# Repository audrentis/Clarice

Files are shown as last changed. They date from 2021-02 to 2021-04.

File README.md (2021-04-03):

# Clarice-F103

## About
An Alice layout PCB based on Yuktsi's files

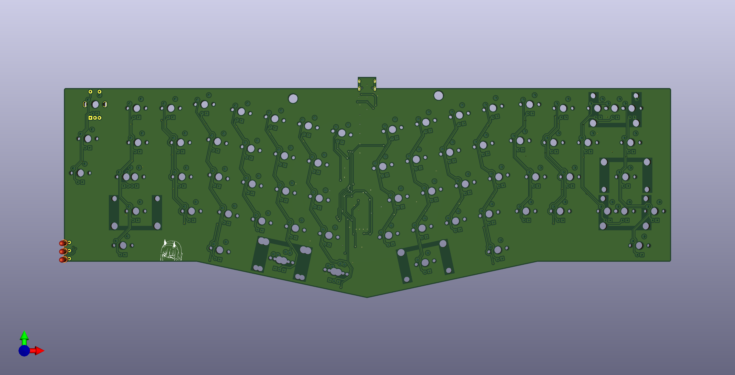
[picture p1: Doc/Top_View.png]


### PCB Features
* Bottom mount USB Type-C 
* Uses STM32F103 MCU
* Support for in-switch LEDs 
* 3 indicator lights in original positions 
* Rotary Encoder footprint at top of macro cluster
* Markings on F.Cu and B.Silks for different switch and stabilizer positions

Uses [xyzz's STM32F103 Bootloader](https://github.com/xyzz/stm32f103-keyboard-bootloader)

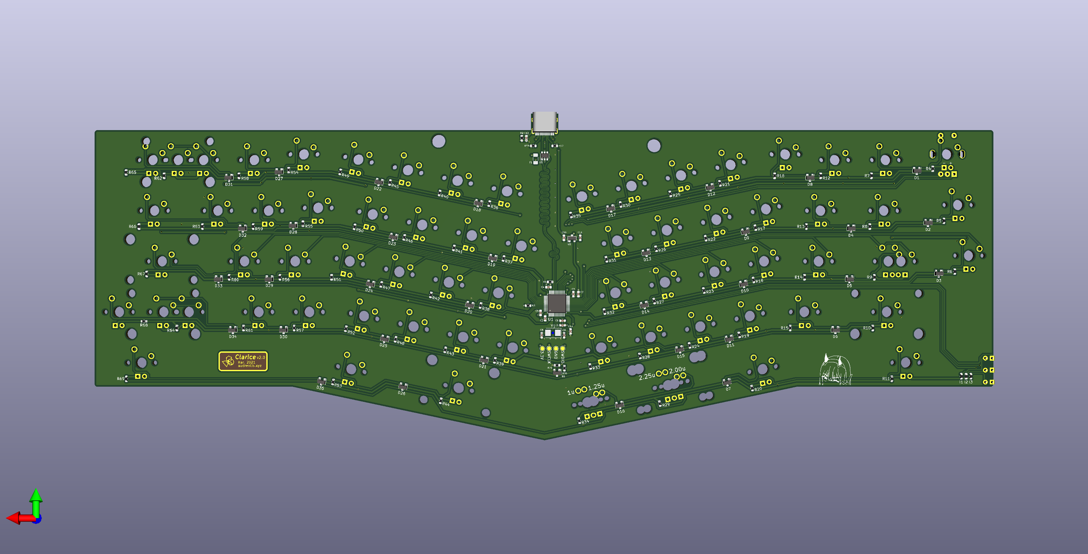
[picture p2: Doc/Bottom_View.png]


### Supported Layouts
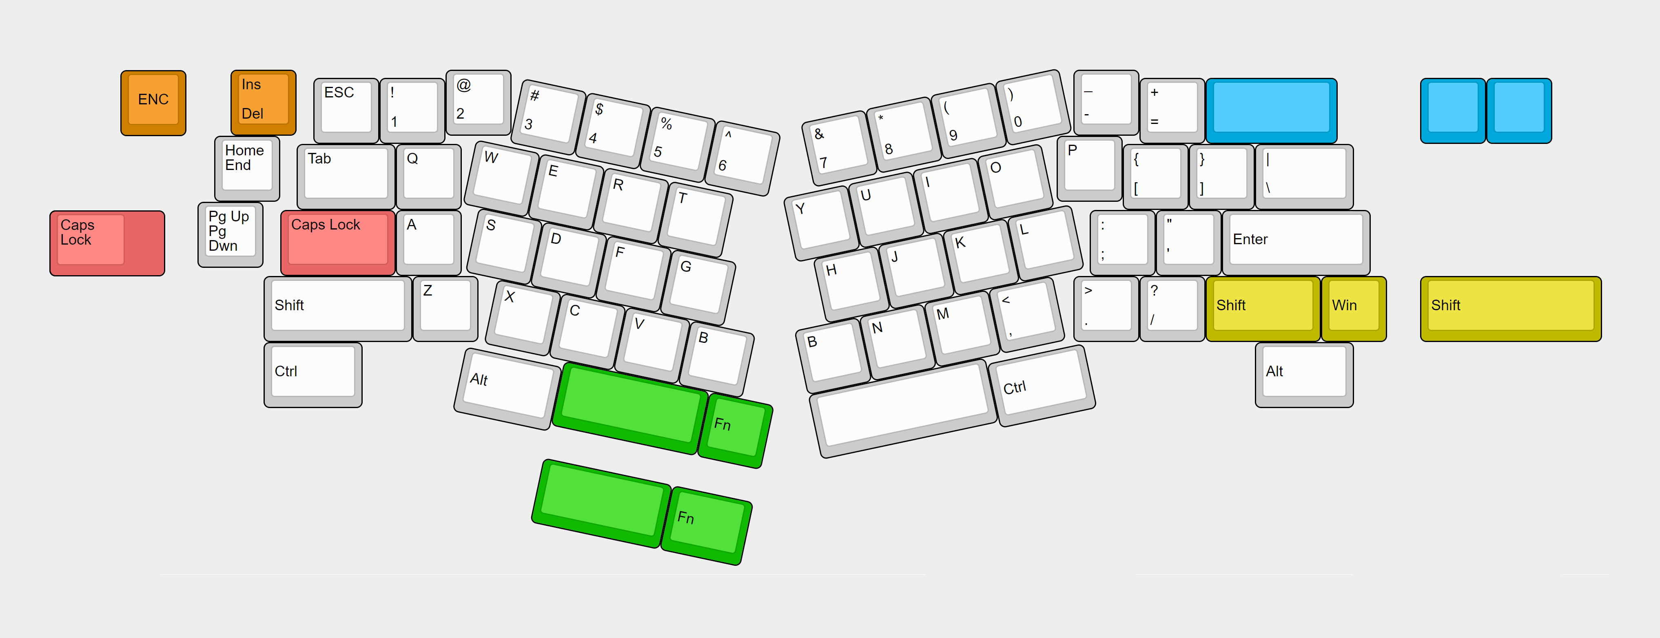
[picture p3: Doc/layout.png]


In the production folder is the files for pcb production from JLCPCB and the raw files for an acrylic case (3mm acrylic layers, 1.5mm switch plate [both half and full plates included])
Doc folder contains firmware 
# Disclaimer
**As stated in the license, I provide these designs as-is and as-available and provide no warranty or guarantees of functionality**  
this is untested and a work in progress. Use these files at your own risk.

# License 
<br />This work is licensed under a <a rel="license" 
href="http://creativecommons.org/licenses/by-nc-sa/4.0/">Creative Commons Attribution-NonCommercial-ShareAlike 4.0 International License</a>.

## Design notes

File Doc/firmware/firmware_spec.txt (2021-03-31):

#define MATRIX_COL_PINS { B2, B1, B0, A7, A6, A5, A4, B11, B8, B7, B6, B5, B4, B3, C14, A15 }
#define MATRIX_ROW_PINS { A10, B10, B9, A3, A2 }

#define LED_CAPS_LOCK_PIN B15
#define LED_NUM_LOCK_PIN B14
#define LED_SCROLL_LOCK_PIN B13

#define BACKLIGHT_PIN A9
#define BACKLIGHT_LEVELS 3
#define BACKLIGHT_ON_STATE 1
#define BACKLIGHT_PWM_DRIVER 
#define BACKLIGHT_PWM_CHANNEL 2

#define ENCODERS_PAD_A { A8 }
#define ENCODERS_PAD_B { B12 }
#define ENCODER_RESOLUTION 1

following const in keymap

void encoder_update_user(uint8_t index, bool clockwise) {
    if (index == 0) { /* First encoder */
        if (clockwise) {
            tap_code(KC_DOWN);
        } else {
            tap_code(KC_UP);
        }
    } else if (index == 1) { /* Second encoder */
        if (clockwise) {
            tap_code(KC_DOWN);
        } else {
            tap_code(KC_UP);
        }
    }
}

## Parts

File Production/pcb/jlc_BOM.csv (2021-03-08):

Comment | Designator | Footprint | LCSC Part #
1 uF | C10, C11, C1 | 603 | C15849
4.7 nF | C12 | 603 | C53987
100 nF | C13 | 603 | C14663
100 nF | C2, C3, C4, C5, C6 | 603 | C14663
10 uF | C7 | 603 | C19702
20 pF | C8, C9 | 603 | C1648
500mA | F1 | 1206 | C369159
1.5k | R1 | 603 | C22843
1M | R2 | 603 | C22935
10k | R3, R71 | 603 | C25804
470 | R4-70, I1, I2, I3 | 603 | C23179
STM32F103CBT6 | U1 | LQFP-48_7.0x7.0x0.5P | C8304
XC6206P332MR | U2 | SOT-23-3L | C5446
SRV05-4-P-T7 | U3 | SOT-23-6L | C85364
X50328MSB2GI | Y1 | SMD-5032_2P | C115962
2N7002 | Q1 | SOT-23-3 | C8545
BAV70 | D1-35 | SOT-23-3 | C68978
HRO-TYPE-C-31-M-12 | USB1 | TYPE-C-31_L8.94_W7.3 | C165948

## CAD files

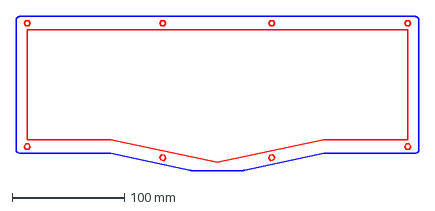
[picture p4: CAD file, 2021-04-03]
Production/acrylic case/close.dxf
358.7 x 137.2 mm

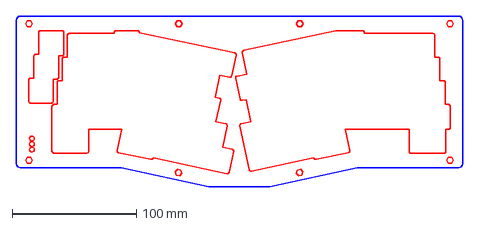
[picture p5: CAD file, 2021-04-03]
Production/acrylic case/btop.dxf
358.7 x 137.2 mm

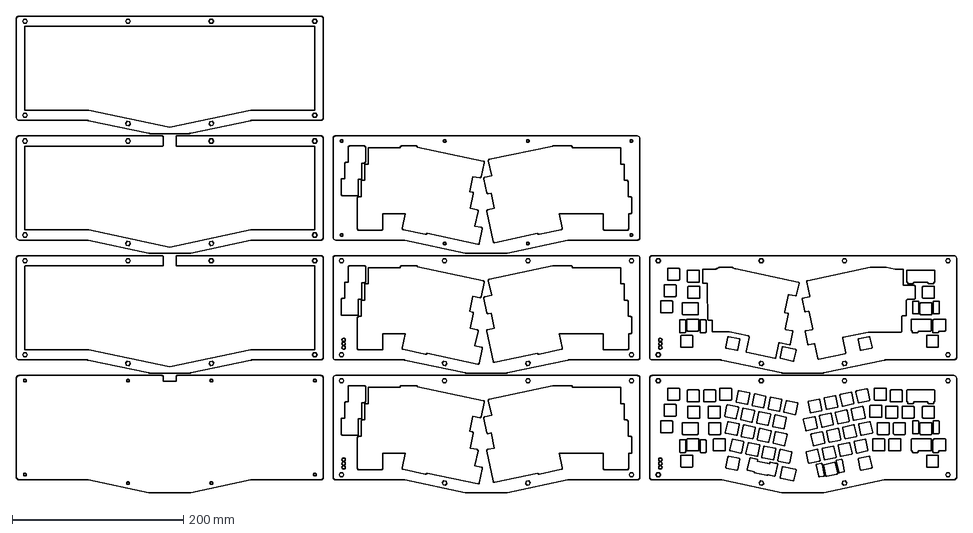
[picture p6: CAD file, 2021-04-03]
Production/acrylic case/caselayers.dxf
1098.7 x 557.2 mm

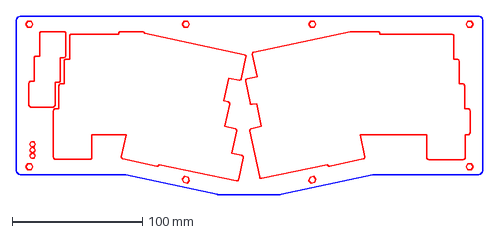
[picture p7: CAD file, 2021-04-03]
Production/acrylic case/mtop.dxf
358.7 x 137.2 mm

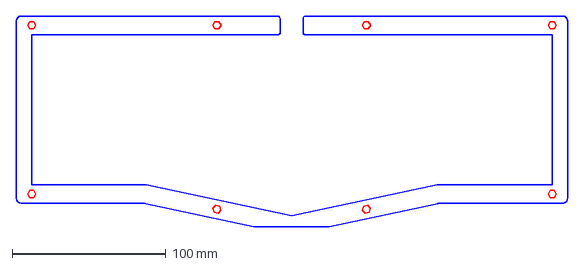
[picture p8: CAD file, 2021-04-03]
Production/acrylic case/o2.dxf
358.7 x 137.2 mm

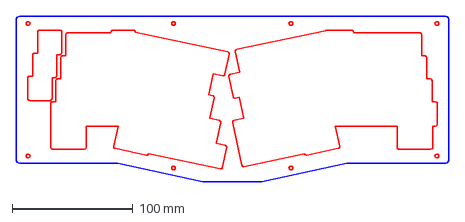
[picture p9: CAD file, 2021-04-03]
Production/acrylic case/ptop.dxf
358.7 x 137.2 mm

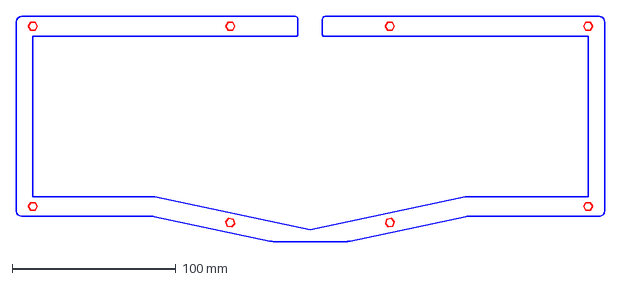
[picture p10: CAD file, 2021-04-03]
Production/acrylic case/o1.dxf
358.7 x 137.2 mm

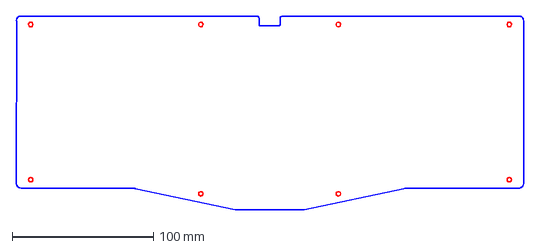
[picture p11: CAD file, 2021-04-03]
Production/acrylic case/bottom.dxf
358.7 x 137.2 mm

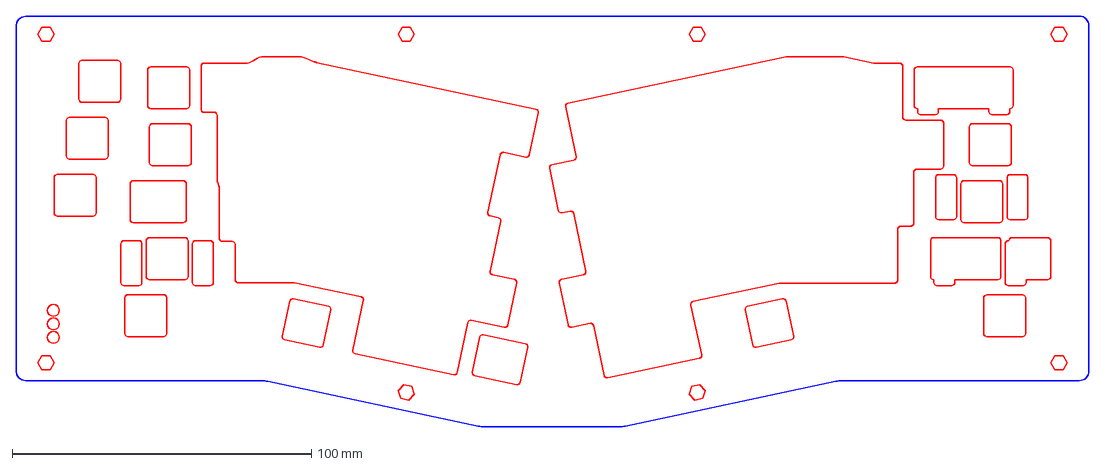
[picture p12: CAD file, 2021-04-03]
Production/acrylic case/hplate.dxf
358.7 x 137.2 mm

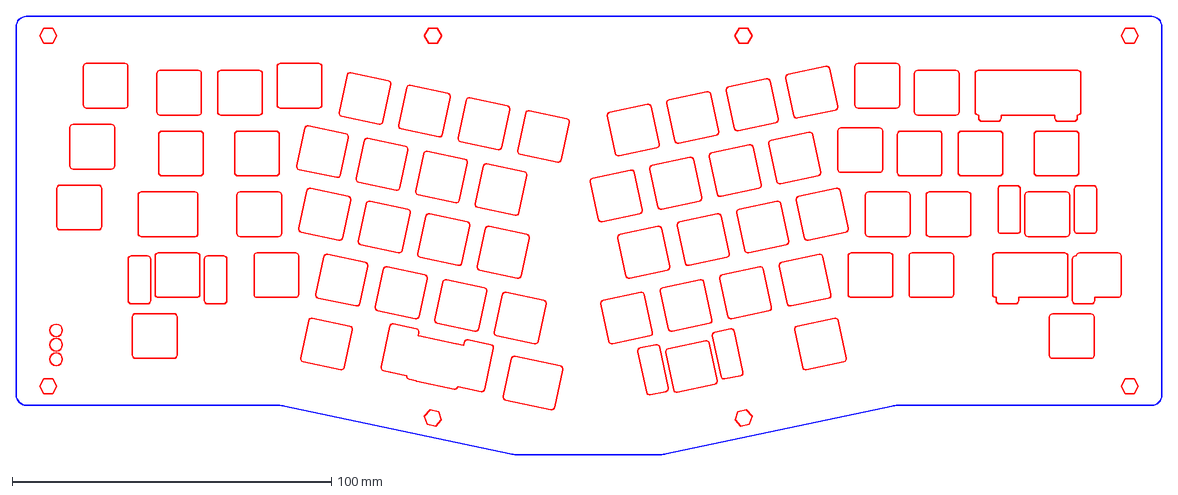
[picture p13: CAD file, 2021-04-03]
Production/acrylic case/fplate.dxf
358.7 x 137.2 mm

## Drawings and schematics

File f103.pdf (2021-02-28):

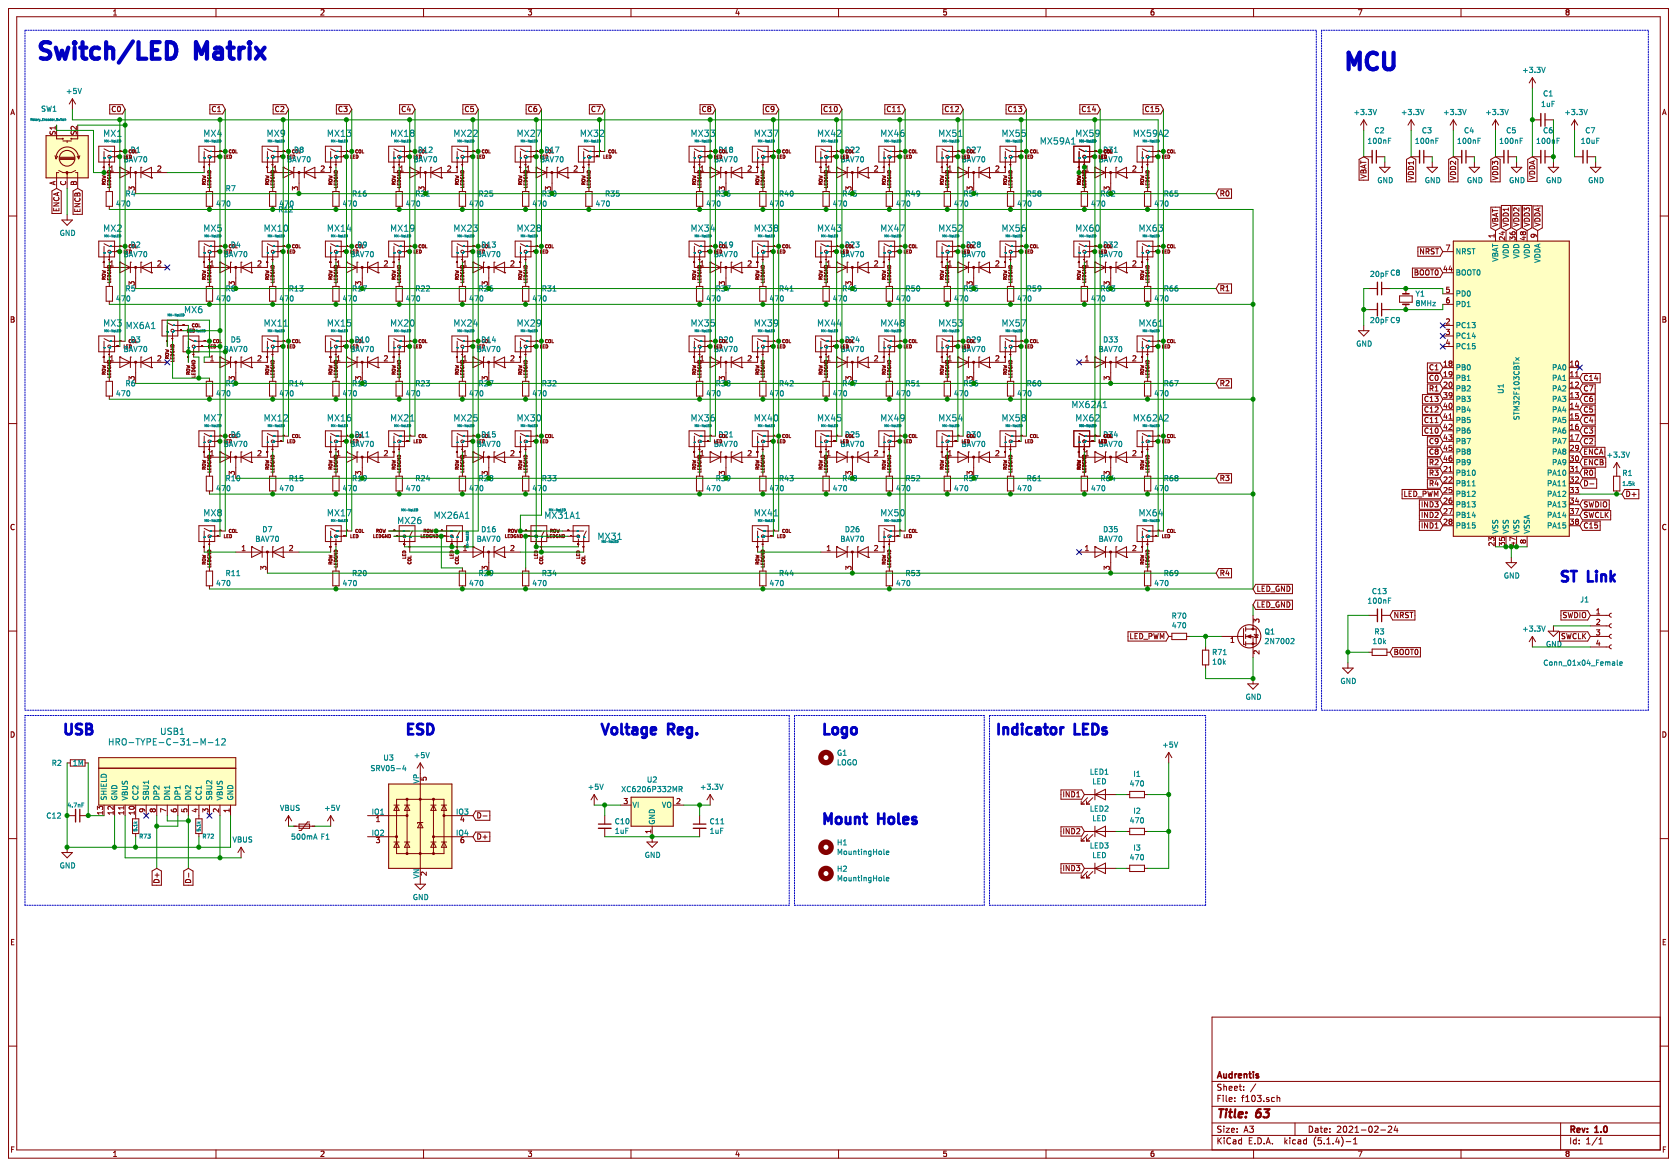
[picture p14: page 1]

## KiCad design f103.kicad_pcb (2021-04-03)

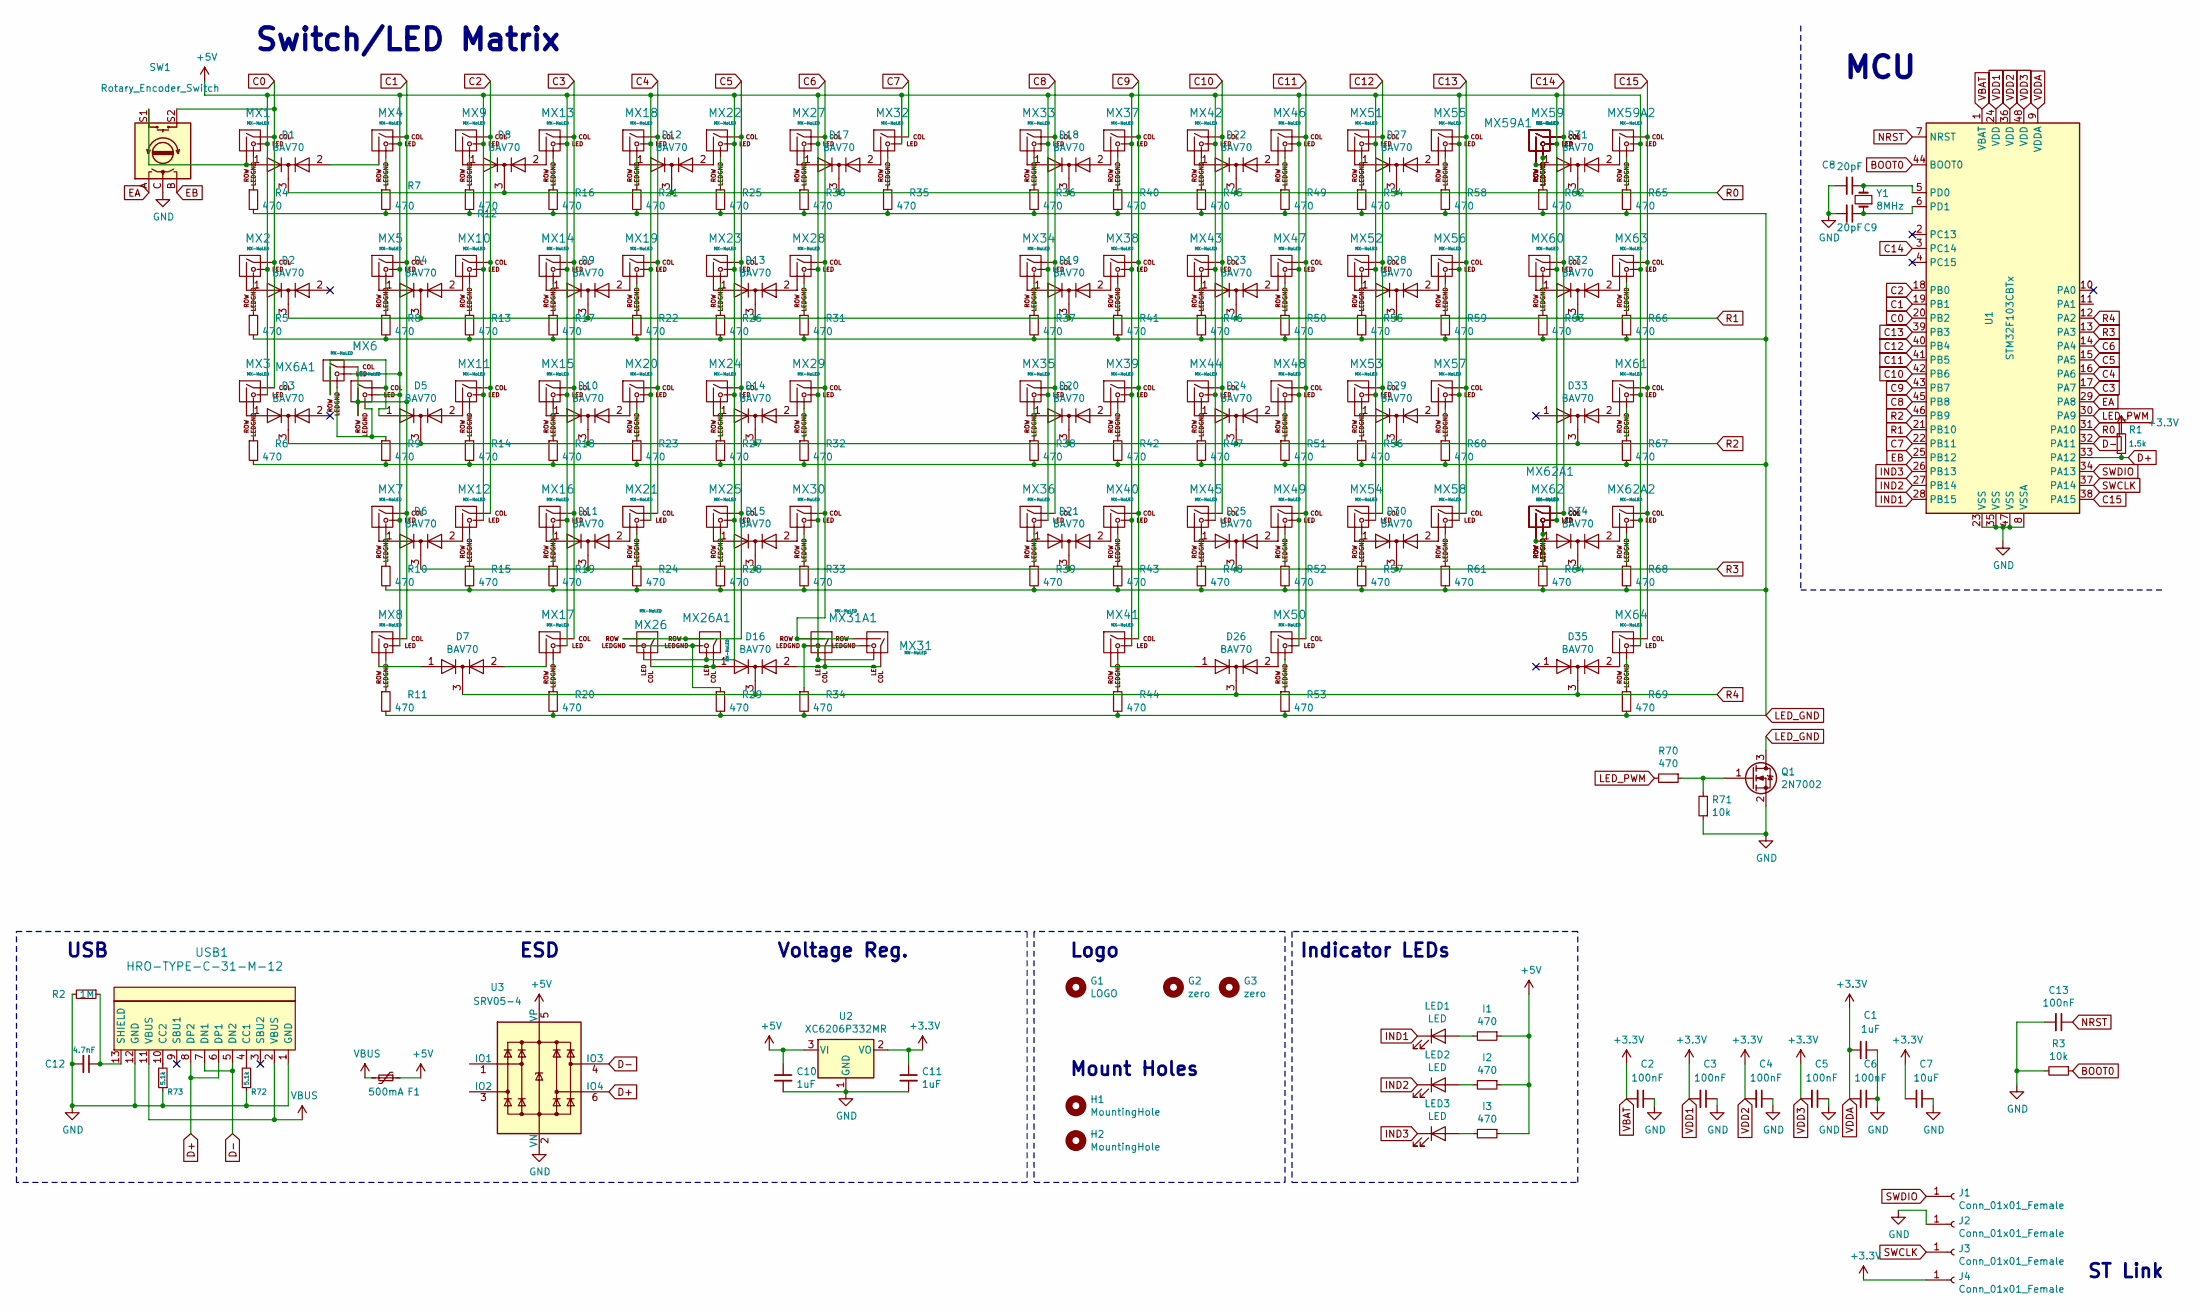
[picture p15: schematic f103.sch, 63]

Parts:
C1, C10, C11: 1uF; C_0603_1608Metric
C2, C3, C4, C5, C6, C13: 100nF; C_0603_1608Metric
C7: 10uF; C_0603_1608Metric
C8, C9: 20pF; C_0603_1608Metric
C12: 4.7nF; C_0603_1608Metric
D1: BAV70; SOT-23; LCSC C68978
D2, D3, D4, D5, D6, D7, D8, D9, D10, D11, D12, D13, D14, D15, D16, D17, D18, D19, D20, D21, D22, D23, D24, D25, D26, D27, D28, D29, D30, D31, D32, D33, D34, D35: BAV70; SOT-23
F1: 500mA; Fuse_1206_3216Metric; Part # C369159
G1: LOGO; Clarice_logo
G2, G3: zero; 0222
H1, H2: MountingHole; MountingHole_5mm
I1, I2, I3: 470; R_0603_1608Metric
J1, J2, J3, J4: Conn_01x01_Female; TestPoint_Pad_D1.5mm
LED1, LED2, LED3: LED; LED_D3.0mm
MX1, MX2, MX3, MX4, MX9, MX10, MX11, MX12, MX13, MX14, MX15, MX16, MX18, MX19, MX20, MX21, MX22, MX23, MX24, MX25, MX27, MX28, MX29, MX30, MX31, MX32, MX33, MX34, MX35, MX36, MX37, MX38, MX39, MX40, MX42, MX43, MX44, MX45, MX46, MX47, MX48, MX49, MX51, MX52, MX53, MX54, MX55, MX56, MX57, MX58, MX59A1, MX59A2, MX60, MX62A2: MX-NoLED; MXOnly-1U
MX5, MX8, MX17, MX50, MX63, MX64: MX-NoLED; MXOnly-1.5U
MX6, MX62A1: MX-NoLED; MXOnly-1.75U
MX6A1, MX31A1: MX-NoLED; MXOnly-1.25U
MX7: MX-NoLED; MXOnly-2.25U
MX26, MX61: MX-NoLED; MXOnly-2.25U-ReversedStabilizers
MX26A1: MX-NoLED; MXOnly-2U-ReversedStabilizers
MX41: MX-NoLED; MXOnly-2.75U-ReversedStabilizers
MX59: MX-NoLED; MXOnly-2U
MX62: MX-NoLED; MXOnly-2.75U
Q1: 2N7002; SOT-23
R1: 1.5k; R_0603_1608Metric
R2: 1M; R_0603_1608Metric
R3, R71: 10k; R_0603_1608Metric
R4: 470; R_0603_1608Metric; LCSC C23179
R5, R6, R7, R8, R9, R10, R11, R12, R13, R14, R15, R16, R17, R18, R19, R20, R21, R22, R23, R24, R25, R26, R27, R28, R29, R30, R31, R32, R33, R34, R35, R36, R37, R38, R39, R40, R41, R42, R43, R44, R45, R46, R47, R48, R49, R50, R51, R52, R53, R54, R55, R56, R57, R58, R59, R60, R61, R62, R63, R64, R65, R66, R67, R68, R69, R70: 470; R_0603_1608Metric
R72, R73: 5.1k; R_0603_1608Metric
SW1: Rotary_Encoder_Switch; RotaryEncoder_Alps_EC11E-Switch_Vertical_H20mm
U1: STM32F103CBTx; LQFP-48_7x7mm_P0.5mm; Part # C8734
U2: XC6206P332MR; SOT-23; Part # C5446
U3: SRV05-4; SOT-23-6; Part # C85364
USB1: HRO-TYPE-C-31-M-12; HRO-TYPE-C-31-M-12-jlc
Y1: 8MHz; Crystal_SMD_5032-2Pin_5.0x3.2mm; Part # C115962

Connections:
+5V: C10.1, F1.1, I1.1, I2.1, I3.1, MX1.3 (LED), MX2.3 (LED), MX3.3 (LED), MX4.3 (LED), MX5.3 (LED), MX6.3 (LED), MX6A1.3 (LED), MX7.3 (LED), MX8.3 (LED), MX9.3 (LED), MX10.3 (LED), MX11.3 (LED), MX12.3 (LED), MX13.3 (LED), MX14.3 (LED), MX15.3 (LED), MX16.3 (LED), MX17.3 (LED), MX18.3 (LED), MX19.3 (LED), MX20.3 (LED), MX21.3 (LED), MX22.3 (LED), MX23.3 (LED), MX24.3 (LED), MX25.3 (LED), MX26.3 (LED), MX26A1.3 (LED), MX27.3 (LED), MX28.3 (LED), MX29.3 (LED), MX30.3 (LED), MX31.3 (LED), MX31A1.3 (LED), MX32.3 (LED), MX33.3 (LED), MX34.3 (LED), MX35.3 (LED), MX36.3 (LED), MX37.3 (LED), MX38.3 (LED), MX39.3 (LED), MX40.3 (LED), MX41.3 (LED), MX42.3 (LED), MX43.3 (LED), MX44.3 (LED), MX45.3 (LED), MX46.3 (LED), MX47.3 (LED), MX48.3 (LED), MX49.3 (LED), MX50.3 (LED), MX51.3 (LED), MX52.3 (LED), MX53.3 (LED), MX54.3 (LED), MX55.3 (LED), MX56.3 (LED), MX57.3 (LED), MX58.3 (LED), MX59.3 (LED), MX59A1.3 (LED), MX59A2.3 (LED), MX60.3 (LED), MX61.3 (LED), MX62.3 (LED), MX62A1.3 (LED), MX62A2.3 (LED), MX63.3 (LED), MX64.3 (LED), U2.3 (VI), U3.5 (VP)
BOOT0: R3.1, U1.44 (BOOT0)
C0: MX1.1 (COL), MX2.1 (COL), MX3.1 (COL), SW1.S2, U1.20 (PB2)
C1: MX4.1 (COL), MX5.1 (COL), MX6.2 (ROW), MX6A1.1 (COL), MX7.1 (COL), MX8.1 (COL), U1.19 (PB1)
C2: MX9.1 (COL), MX10.1 (COL), MX11.1 (COL), MX12.1 (COL), U1.18 (PB0)
C3: MX13.1 (COL), MX14.1 (COL), MX15.1 (COL), MX16.1 (COL), MX17.1 (COL), U1.17 (PA7)
C4: MX18.1 (COL), MX19.1 (COL), MX20.1 (COL), MX21.1 (COL), U1.16 (PA6)
C5: MX22.1 (COL), MX23.1 (COL), MX24.1 (COL), MX25.1 (COL), MX26.2 (ROW), MX26A1.2 (ROW), U1.15 (PA5)
C6: MX27.1 (COL), MX28.1 (COL), MX29.1 (COL), MX30.1 (COL), MX31.2 (ROW), MX31A1.2 (ROW), U1.14 (PA4)
C7: MX32.1 (COL), U1.22 (PB11)
C8: MX33.1 (COL), MX34.1 (COL), MX35.1 (COL), MX36.1 (COL), U1.45 (PB8)
C9: MX37.1 (COL), MX38.1 (COL), MX39.1 (COL), MX40.1 (COL), MX41.1 (COL), U1.43 (PB7)
C10: MX42.1 (COL), MX43.1 (COL), MX44.1 (COL), MX45.1 (COL), U1.42 (PB6)
C11: MX46.1 (COL), MX47.1 (COL), MX48.1 (COL), MX49.1 (COL), MX50.1 (COL), U1.41 (PB5)
C12: MX51.1 (COL), MX52.1 (COL), MX53.1 (COL), MX54.1 (COL), U1.40 (PB4)
C13: MX55.1 (COL), MX56.1 (COL), MX57.1 (COL), MX58.1 (COL), U1.39 (PB3)
C14: MX59.1 (COL), MX59A1.1 (COL), MX60.1 (COL), MX62.1 (COL), MX62A1.1 (COL), U1.3 (PC14)
C15: MX59A2.1 (COL), MX61.1 (COL), MX62A2.1 (COL), MX63.1 (COL), MX64.1 (COL), U1.38 (PA15)
D+: R1.2, U1.33 (PA12), U3.6 (IO4), USB1.6 (DP1), USB1.8 (DP2)
D-: U1.32 (PA11), U3.4 (IO3), USB1.5 (DN2), USB1.7 (DN1)
EA: SW1.A, U1.29 (PA8)
EB: SW1.B, U1.25 (PB12)
GND: C1.1, C2.1, C3.1, C4.1, C5.1, C6.1, C7.1, C8.2, C9.2, C10.2, C11.2, C12.2, C13.2, J2.1, Q1.2 (S), R2.2, R3.2, R71.1, R72.1, R73.1, SW1.C, U1.8 (VSSA), U1.23 (VSS), U1.35 (VSS), U1.47 (VSS), U2.1 (GND), U3.2 (VN), USB1.1 (GND), USB1.12 (GND)
IND1: LED1.1 (K), U1.28 (PB15)
IND2: LED2.1 (K), U1.27 (PB14)
IND3: LED3.1 (K), U1.26 (PB13)
LED_GND: Q1.3 (D), R4.2, R5.2, R6.2, R7.2, R8.2, R9.2, R10.2, R11.2, R12.2, R13.2, R14.2, R15.2, R16.2, R17.2, R18.2, R19.2, R20.2, R21.2, R22.2, R23.2, R24.2, R25.2, R26.2, R27.2, R28.2, R29.2, R30.2, R31.2, R32.2, R33.2, R34.2, R35.2, R36.2, R37.2, R38.2, R39.2, R40.2, R41.2, R42.2, R43.2, R44.2, R45.2, R46.2, R47.2, R48.2, R49.2, R50.2, R51.2, R52.2, R53.2, R54.2, R55.2, R56.2, R57.2, R58.2, R59.2, R60.2, R61.2, R62.2, R63.2, R64.2, R65.2, R66.2, R67.2, R68.2, R69.2
LED_PWM: R70.2, U1.30 (PA9)
NRST: C13.1, U1.7 (NRST)
unnamed: C8.1, U1.5 (PD0), Y1.2
unnamed: C9.1, U1.6 (PD1), Y1.1
unnamed: C12.1, R2.1, USB1.13 (SHIELD)
unnamed: D1.1 (A), MX1.2 (ROW), SW1.S1
unnamed: D1.2 (A), MX4.2 (ROW)
unnamed: D2.1 (A), MX2.2 (ROW)
unnamed: D3.1 (A), MX3.2 (ROW)
unnamed: D4.1 (A), MX5.2 (ROW)
unnamed: D4.2 (A), MX10.2 (ROW)
unnamed: D5.1 (A), MX6.1 (COL), MX6A1.2 (ROW)
unnamed: D5.2 (A), MX11.2 (ROW)
unnamed: D6.1 (A), MX7.2 (ROW)
unnamed: D6.2 (A), MX12.2 (ROW)
unnamed: D7.1 (A), MX8.2 (ROW)
unnamed: D7.2 (A), MX17.2 (ROW)
unnamed: D8.1 (A), MX9.2 (ROW)
unnamed: D8.2 (A), MX13.2 (ROW)
unnamed: D9.1 (A), MX14.2 (ROW)
unnamed: D9.2 (A), MX19.2 (ROW)
unnamed: D10.1 (A), MX15.2 (ROW)
unnamed: D10.2 (A), MX20.2 (ROW)
unnamed: D11.1 (A), MX16.2 (ROW)
unnamed: D11.2 (A), MX21.2 (ROW)
unnamed: D12.1 (A), MX18.2 (ROW)
unnamed: D12.2 (A), MX22.2 (ROW)
unnamed: D13.1 (A), MX23.2 (ROW)
unnamed: D13.2 (A), MX28.2 (ROW)
unnamed: D14.1 (A), MX24.2 (ROW)
unnamed: D14.2 (A), MX29.2 (ROW)
unnamed: D15.1 (A), MX25.2 (ROW)
unnamed: D15.2 (A), MX30.2 (ROW)
unnamed: D16.1 (A), MX26.1 (COL), MX26A1.1 (COL)
unnamed: D16.2 (A), MX31.1 (COL), MX31A1.1 (COL)
unnamed: D17.1 (A), MX27.2 (ROW)
unnamed: D17.2 (A), MX32.2 (ROW)
unnamed: D18.1 (A), MX33.2 (ROW)
unnamed: D18.2 (A), MX37.2 (ROW)
unnamed: D19.1 (A), MX34.2 (ROW)
unnamed: D19.2 (A), MX38.2 (ROW)
unnamed: D20.1 (A), MX35.2 (ROW)
unnamed: D20.2 (A), MX39.2 (ROW)
unnamed: D21.1 (A), MX36.2 (ROW)
unnamed: D21.2 (A), MX40.2 (ROW)
unnamed: D22.1 (A), MX42.2 (ROW)
unnamed: D22.2 (A), MX46.2 (ROW)
unnamed: D23.1 (A), MX43.2 (ROW)
unnamed: D23.2 (A), MX47.2 (ROW)
unnamed: D24.1 (A), MX44.2 (ROW)
unnamed: D24.2 (A), MX48.2 (ROW)
unnamed: D25.1 (A), MX45.2 (ROW)
unnamed: D25.2 (A), MX49.2 (ROW)
unnamed: D26.1 (A), MX41.2 (ROW)
unnamed: D26.2 (A), MX50.2 (ROW)
unnamed: D27.1 (A), MX51.2 (ROW)
unnamed: D27.2 (A), MX55.2 (ROW)
unnamed: D28.1 (A), MX52.2 (ROW)
unnamed: D28.2 (A), MX56.2 (ROW)
unnamed: D29.1 (A), MX53.2 (ROW)
unnamed: D29.2 (A), MX57.2 (ROW)
unnamed: D30.1 (A), MX54.2 (ROW)
unnamed: D30.2 (A), MX58.2 (ROW)
unnamed: D31.1 (A), MX59.2 (ROW), MX59A1.2 (ROW)
unnamed: D31.2 (A), MX59A2.2 (ROW)
unnamed: D32.1 (A), MX60.2 (ROW)
unnamed: D32.2 (A), MX63.2 (ROW)
unnamed: D33.2 (A), MX61.2 (ROW)
unnamed: D34.1 (A), MX62.2 (ROW), MX62A1.2 (ROW)
unnamed: D34.2 (A), MX62A2.2 (ROW)
unnamed: D35.2 (A), MX64.2 (ROW)
unnamed: I1.2, LED1.2 (A)
unnamed: I2.2, LED2.2 (A)
unnamed: I3.2, LED3.2 (A)
unnamed: MX1.4 (LEDGND), R4.1
unnamed: MX2.4 (LEDGND), R5.1
unnamed: MX3.4 (LEDGND), R6.1
unnamed: MX4.4 (LEDGND), R7.1
unnamed: MX5.4 (LEDGND), R8.1
unnamed: MX6.4 (LEDGND), MX6A1.4 (LEDGND), R9.1
unnamed: MX7.4 (LEDGND), R10.1
unnamed: MX8.4 (LEDGND), R11.1
unnamed: MX9.4 (LEDGND), R12.1
unnamed: MX10.4 (LEDGND), R13.1
unnamed: MX11.4 (LEDGND), R14.1
unnamed: MX12.4 (LEDGND), R15.1
unnamed: MX13.4 (LEDGND), R16.1
unnamed: MX14.4 (LEDGND), R17.1
unnamed: MX15.4 (LEDGND), R18.1
unnamed: MX16.4 (LEDGND), R19.1
unnamed: MX17.4 (LEDGND), R20.1
unnamed: MX18.4 (LEDGND), R21.1
unnamed: MX19.4 (LEDGND), R22.1
unnamed: MX20.4 (LEDGND), R23.1
unnamed: MX21.4 (LEDGND), R24.1
unnamed: MX22.4 (LEDGND), R25.1
unnamed: MX23.4 (LEDGND), R26.1
unnamed: MX24.4 (LEDGND), R27.1
unnamed: MX25.4 (LEDGND), R28.1
unnamed: MX26.4 (LEDGND), MX26A1.4 (LEDGND), R29.1
unnamed: MX27.4 (LEDGND), R30.1
unnamed: MX28.4 (LEDGND), R31.1
unnamed: MX29.4 (LEDGND), R32.1
unnamed: MX30.4 (LEDGND), R33.1
unnamed: MX31.4 (LEDGND), MX31A1.4 (LEDGND), R34.1
unnamed: MX32.4 (LEDGND), R35.1
unnamed: MX33.4 (LEDGND), R36.1
unnamed: MX34.4 (LEDGND), R37.1
unnamed: MX35.4 (LEDGND), R38.1
unnamed: MX36.4 (LEDGND), R39.1
unnamed: MX37.4 (LEDGND), R40.1
unnamed: MX38.4 (LEDGND), R41.1
unnamed: MX39.4 (LEDGND), R42.1
unnamed: MX40.4 (LEDGND), R43.1
unnamed: MX41.4 (LEDGND), R44.1
unnamed: MX42.4 (LEDGND), R45.1
unnamed: MX43.4 (LEDGND), R46.1
unnamed: MX44.4 (LEDGND), R47.1
unnamed: MX45.4 (LEDGND), R48.1
unnamed: MX46.4 (LEDGND), R49.1
unnamed: MX47.4 (LEDGND), R50.1
unnamed: MX48.4 (LEDGND), R51.1
unnamed: MX49.4 (LEDGND), R52.1
unnamed: MX50.4 (LEDGND), R53.1
unnamed: MX51.4 (LEDGND), R54.1
unnamed: MX52.4 (LEDGND), R55.1
unnamed: MX53.4 (LEDGND), R56.1
unnamed: MX54.4 (LEDGND), R57.1
unnamed: MX55.4 (LEDGND), R58.1
unnamed: MX56.4 (LEDGND), R59.1
unnamed: MX57.4 (LEDGND), R60.1
unnamed: MX58.4 (LEDGND), R61.1
unnamed: MX59.4 (LEDGND), MX59A1.4 (LEDGND), R62.1
unnamed: MX59A2.4 (LEDGND), R65.1
unnamed: MX60.4 (LEDGND), R63.1
unnamed: MX61.4 (LEDGND), R67.1
unnamed: MX62.4 (LEDGND), MX62A1.4 (LEDGND), R64.1
unnamed: MX62A2.4 (LEDGND), R68.1
unnamed: MX63.4 (LEDGND), R66.1
unnamed: MX64.4 (LEDGND), R69.1
unnamed: Q1.1 (G), R70.1, R71.2
unnamed: R72.2, USB1.4 (CC1)
unnamed: R73.2, USB1.10 (CC2)
R0: D1.3 (K), D8.3 (K), D12.3 (K), D17.3 (K), D18.3 (K), D22.3 (K), D27.3 (K), D31.3 (K), U1.31 (PA10)
R1: D2.3 (K), D4.3 (K), D9.3 (K), D13.3 (K), D19.3 (K), D23.3 (K), D28.3 (K), D32.3 (K), U1.21 (PB10)
R2: D3.3 (K), D5.3 (K), D10.3 (K), D14.3 (K), D20.3 (K), D24.3 (K), D29.3 (K), D33.3 (K), U1.46 (PB9)
R3: D6.3 (K), D11.3 (K), D15.3 (K), D21.3 (K), D25.3 (K), D30.3 (K), D34.3 (K), U1.13 (PA3)
R4: D7.3 (K), D16.3 (K), D26.3 (K), D35.3 (K), U1.12 (PA2)
SWCLK: J3.1, U1.37 (PA14)
SWDIO: J1.1, U1.34 (PA13)
VBAT: C1.2, C2.2, C3.2, C4.2, C5.2, C6.2, C7.2, C11.1, J4.1, R1.1, U1.1 (VBAT), U1.9 (VDDA), U1.24 (VDD), U1.36 (VDD), U1.48 (VDD), U2.2 (VO)
VBUS: F1.2, USB1.2 (VBUS), USB1.11 (VBUS)

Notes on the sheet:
Switch/LED Matrix
MCU
ST Link
USB
Voltage Reg.
ESD
Logo
Mount Holes
Indicator LEDs

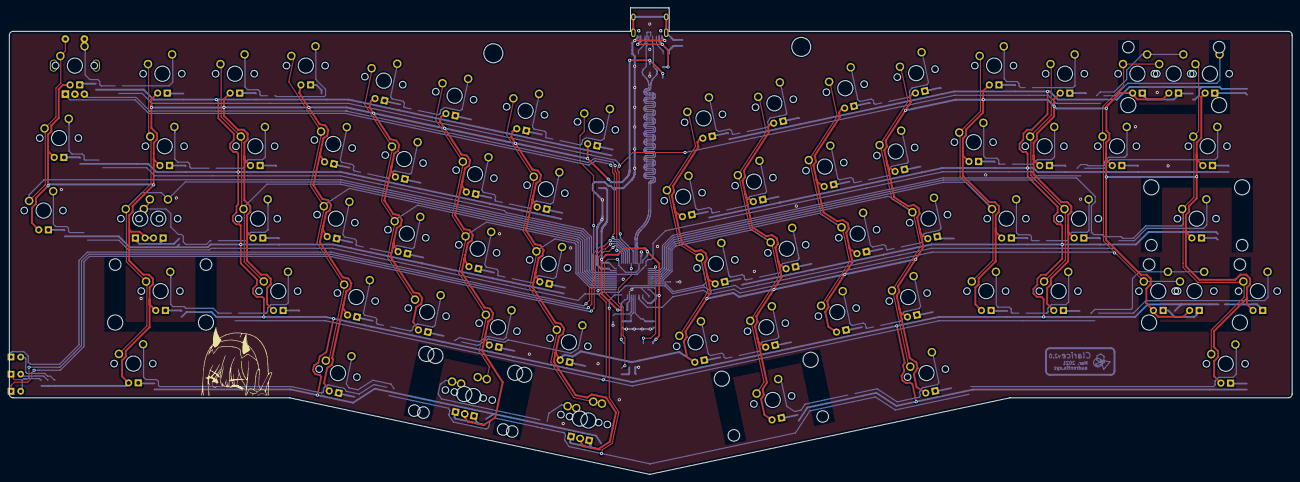
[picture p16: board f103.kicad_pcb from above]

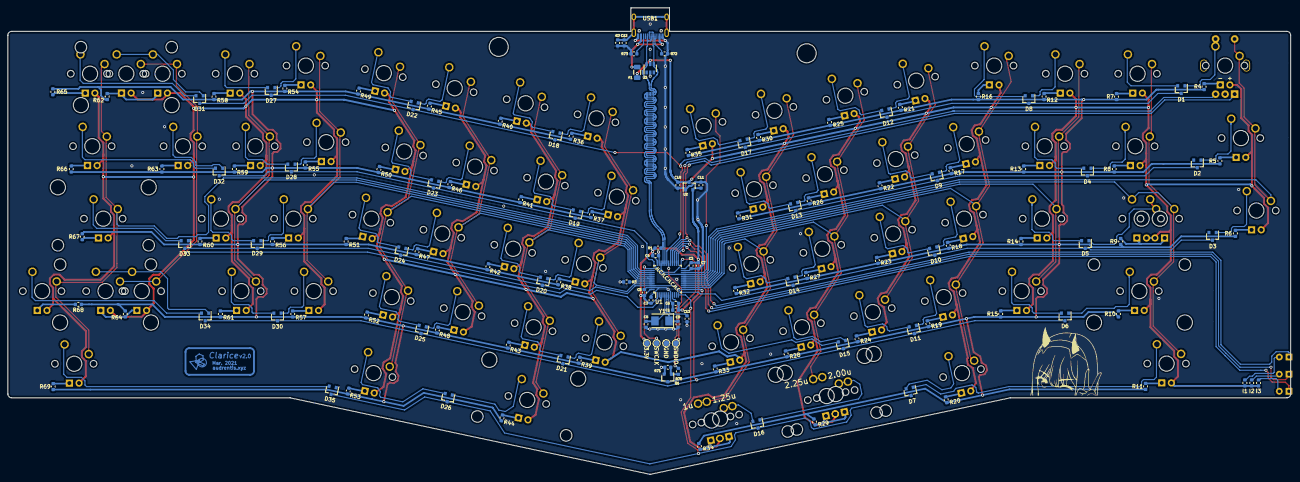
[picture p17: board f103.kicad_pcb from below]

Board: 2 copper layers, 337.2 x 122.6 mm, 215 parts (136 on the bottom side), 179 nets.

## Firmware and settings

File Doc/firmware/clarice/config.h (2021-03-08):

/*
Copyright 2020 Bryan Ong

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
You should have received a copy of the GNU General Public License
along with this program.  If not, see <http://www.gnu.org/licenses/>.
*/

#pragma once

#include "config_common.h"

/* USB Device descriptor parameter */
#define VENDOR_ID       0xFEED //fix later 
#define PRODUCT_ID      0xFEED //fix later
#define DEVICE_VER      0x0001 
#define MANUFACTURER    Audrentis
#define PRODUCT         Clarice

/*Bootmagic boot button, set to topmost, leftmost key */
#define BOOTMAGIC_LITE_ROW	2
#define BOOTMAGIC_LITE_COLUMN	0

/* encoder */
/* #define NUMBER_OF_ENCODERS 1 */
#define ENCODERS_PAD_A { A8 }
#define ENCODERS_PAD_B { A9 }
#define ENCODER_RESOLUTION 1

/* key matrix size */
#define MATRIX_ROWS 5
#define MATRIX_COLS 16

/* key matrix pins */
#define MATRIX_COL_PINS { B2, B1, B0, A7, A6, A5, A4, B11, B8, B7, B6, B5, B4, B3, C14, A15 }
#define MATRIX_ROW_PINS { A10, B10, B9, A3, A2 }
#define UNUSED_PINS

/* COL2ROW or ROW2COL */
#define DIODE_DIRECTION COL2ROW

/* Set 0 if debouncing isn't needed */
#define DEBOUNCE 5

/* Mechanical locking support. Use KC_LCAP, KC_LNUM or KC_LSCR instead in keymap */
#define LOCKING_SUPPORT_ENABLE

/* Locking resynchronize hack */
#define LOCKING_RESYNC_ENABLE


#define BACKLIGHT_PIN B12
#define BACKLIGHT_LEVELS 3
#define BACKLIGHT_ON_STATE 1
#define BACKLIGHT_PWM_DRIVER 
#define BACKLIGHT_PWM_CHANNEL 

#ifdef RGB_DI_PIN
#define RGBLIGHT_ANIMATIONS
#define RGBLED_NUM 0
#define RGBLIGHT_HUE_STEP 8
#define RGBLIGHT_SAT_STEP 8
#define RGBLIGHT_VAL_STEP 8
#endif

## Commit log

2021-01-20 add proj
    [f103-B_Cu.gbr, f103-B_Mask.gbr, f103-B_SilkS.gbr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]
2021-01-20 Add Production Files, Submit for review
    [f103-B_Cu.gbr, f103-B_Mask.gbr, f103-B_SilkS.gbr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]
2021-01-28 DRC I
    [f103.kicad_pcb, f103.sch]
2021-02-02 DRC II
    update silks and ground planes
    [f103.kicad_pcb]
2021-02-03 DRC III
    Switch to usb type-C
    [f103-B_Cu.gbr, f103-B_Mask.gbr, f103-B_SilkS.gbr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]
2021-02-08 DRC IV
    [f103.kicad_pcb, f103.sch]
2021-02-21 Checking Datasheet
    [f103.kicad_pcb, f103.sch]
2021-02-28 DRC Pass
    [f103.kicad_pcb, f103.sch]
2021-03-08 Finalizing
    - Firmware creation begun
    - add .step model of PCB
    - add gerbers, CPL, BOM
    [f103-B_Cu.gbr, f103-B_Mask.gbr, f103-B_SilkS.gbr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]
2021-03-31 overhaul: see description
    - remapped backlighting to A9
    - remapped encoder pad B to B12
    - updated ground fills
    - added 02 silkscreen
    - write firmware
    - add compiled binary file
    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
    [f103-B_Cu.gbr, f103-B_Mask.gbr, f103-B_SilkS.gbr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]
2021-04-03 ordered prototypes
    [bottom.dxf, btop.dxf, caselayers.dxf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]

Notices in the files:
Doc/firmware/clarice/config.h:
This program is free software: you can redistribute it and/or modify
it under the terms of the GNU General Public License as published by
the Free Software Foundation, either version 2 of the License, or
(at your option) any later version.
